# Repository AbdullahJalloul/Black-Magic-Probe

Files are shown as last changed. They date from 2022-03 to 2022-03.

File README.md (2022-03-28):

# ISO Black Magic Probe

**Black Magic Probe hardware features:**

*  On board implementation of JTAG (Joint Test Access Group) protocol
*  On board implementation of the SWD (Serial Wire Debug) protocol
*  High speed data interface to the Device Under Test 4.5MBit
*  On board implementation of the GNU Debugger Server protocol (no need for OpenOCD) works with stock arm-none-eabi-gdb (no patches or plugins needed)
*  Automatic detection of the Device Under Test (no need for config files)
*  Frontend Level shifter. Usable with targets that run on voltages as low as 1.7V and as high as 5V.
*  There is experimental support for Cortex-A (ARMv7-A architecture). This is being used with success on Xilinx Zynq-7000 SoC (Dual-core Cortex-A9) and Raspberry Pi 2 (Quad-core Cortex-A7).
*  Semihosting IO support (allows execution of print, read, open, system calls on the host through the JTAG/SWD interface)
*  Interface to the host computer is a standard USB CDC ACM device (virtual serial port), which does not require special drivers on Linux or MacOS.
*  Auxiliary UART interface. Black Magic Probe can be used as a USB to Serial adapter at the same time together with the JTAG/SWD interface.
*  Implements USB DFU class for easy firmware upgrade as updates become available.
*  Works with Windows, Linux and MacOS environments.

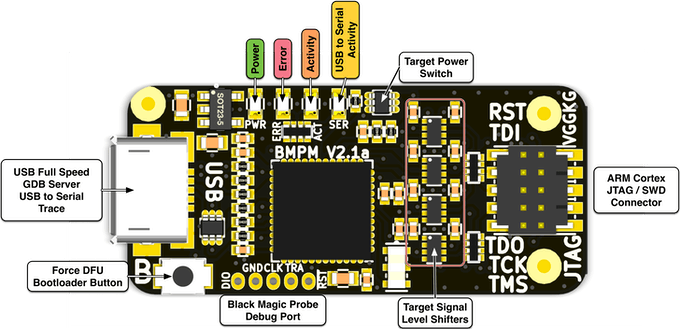
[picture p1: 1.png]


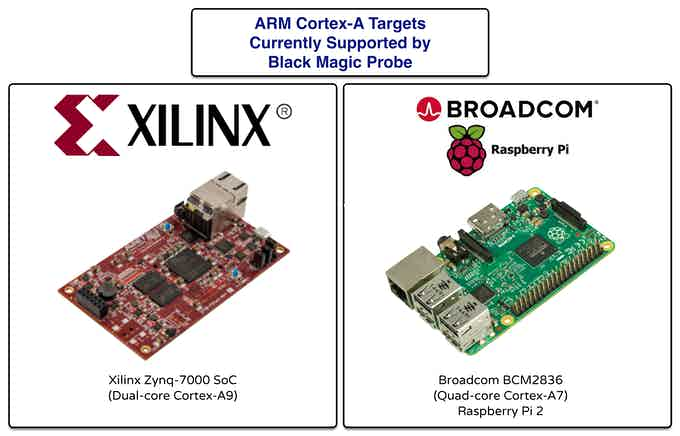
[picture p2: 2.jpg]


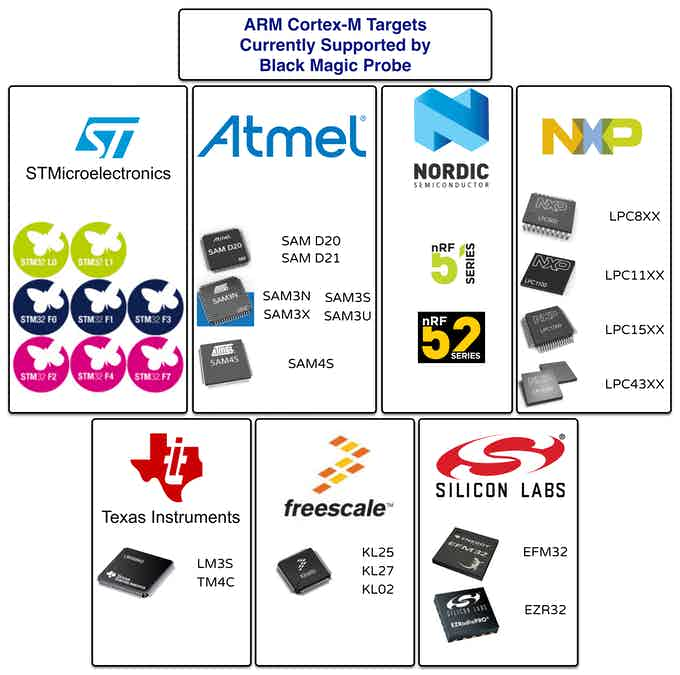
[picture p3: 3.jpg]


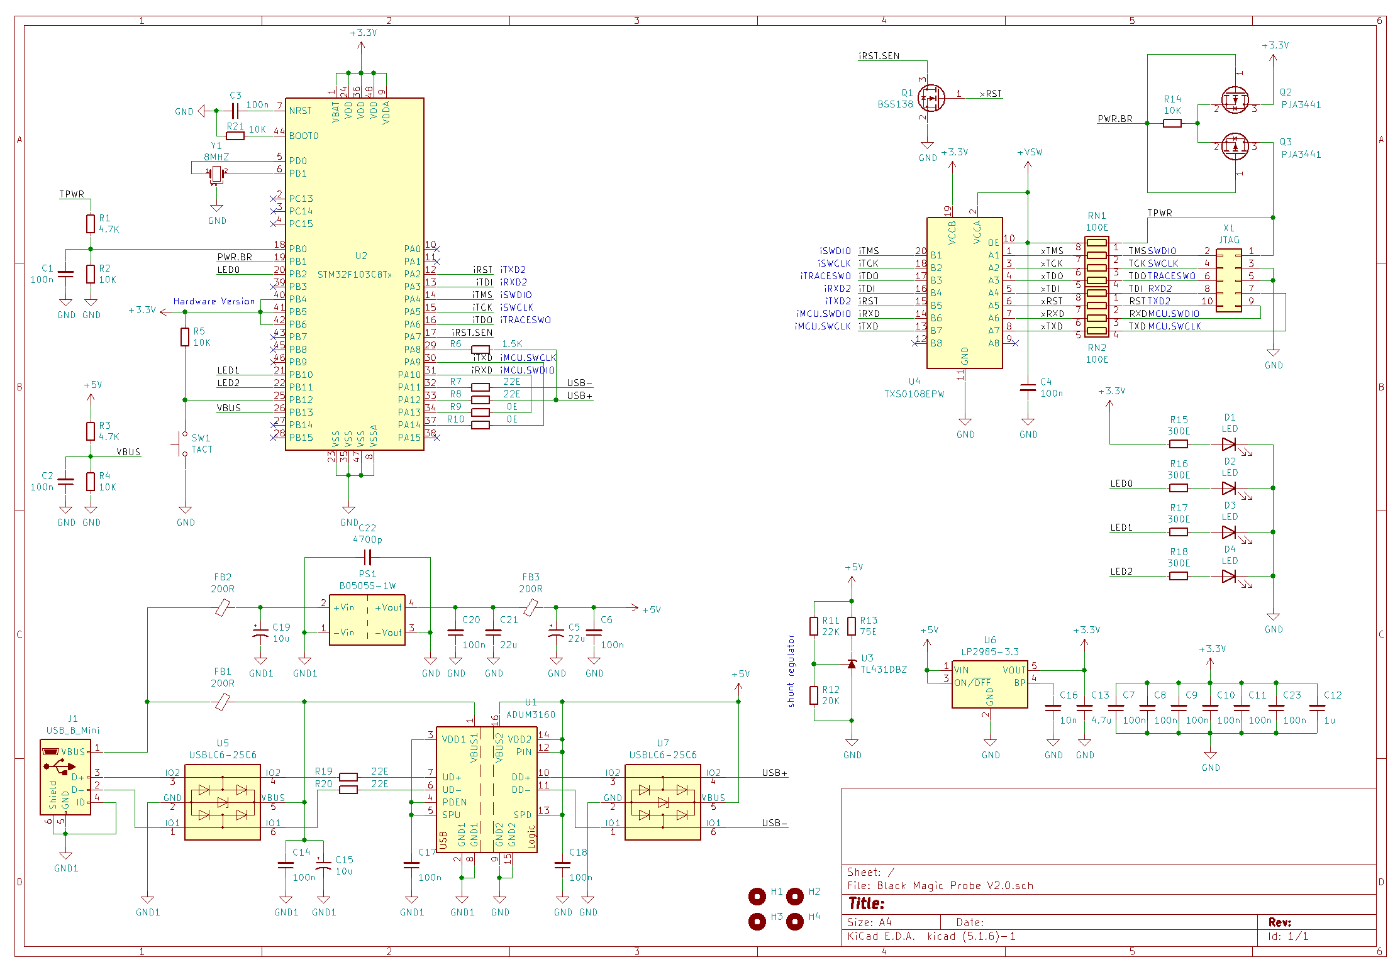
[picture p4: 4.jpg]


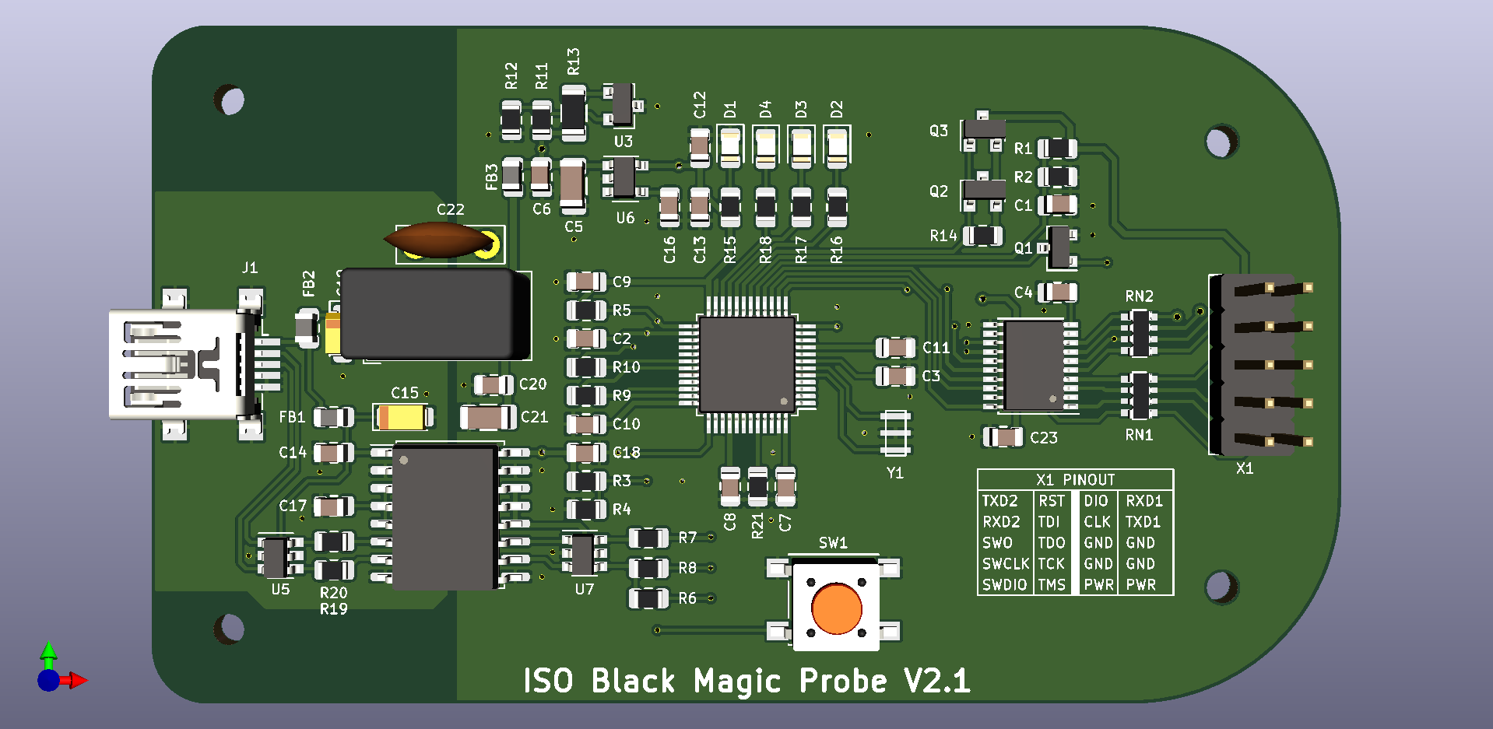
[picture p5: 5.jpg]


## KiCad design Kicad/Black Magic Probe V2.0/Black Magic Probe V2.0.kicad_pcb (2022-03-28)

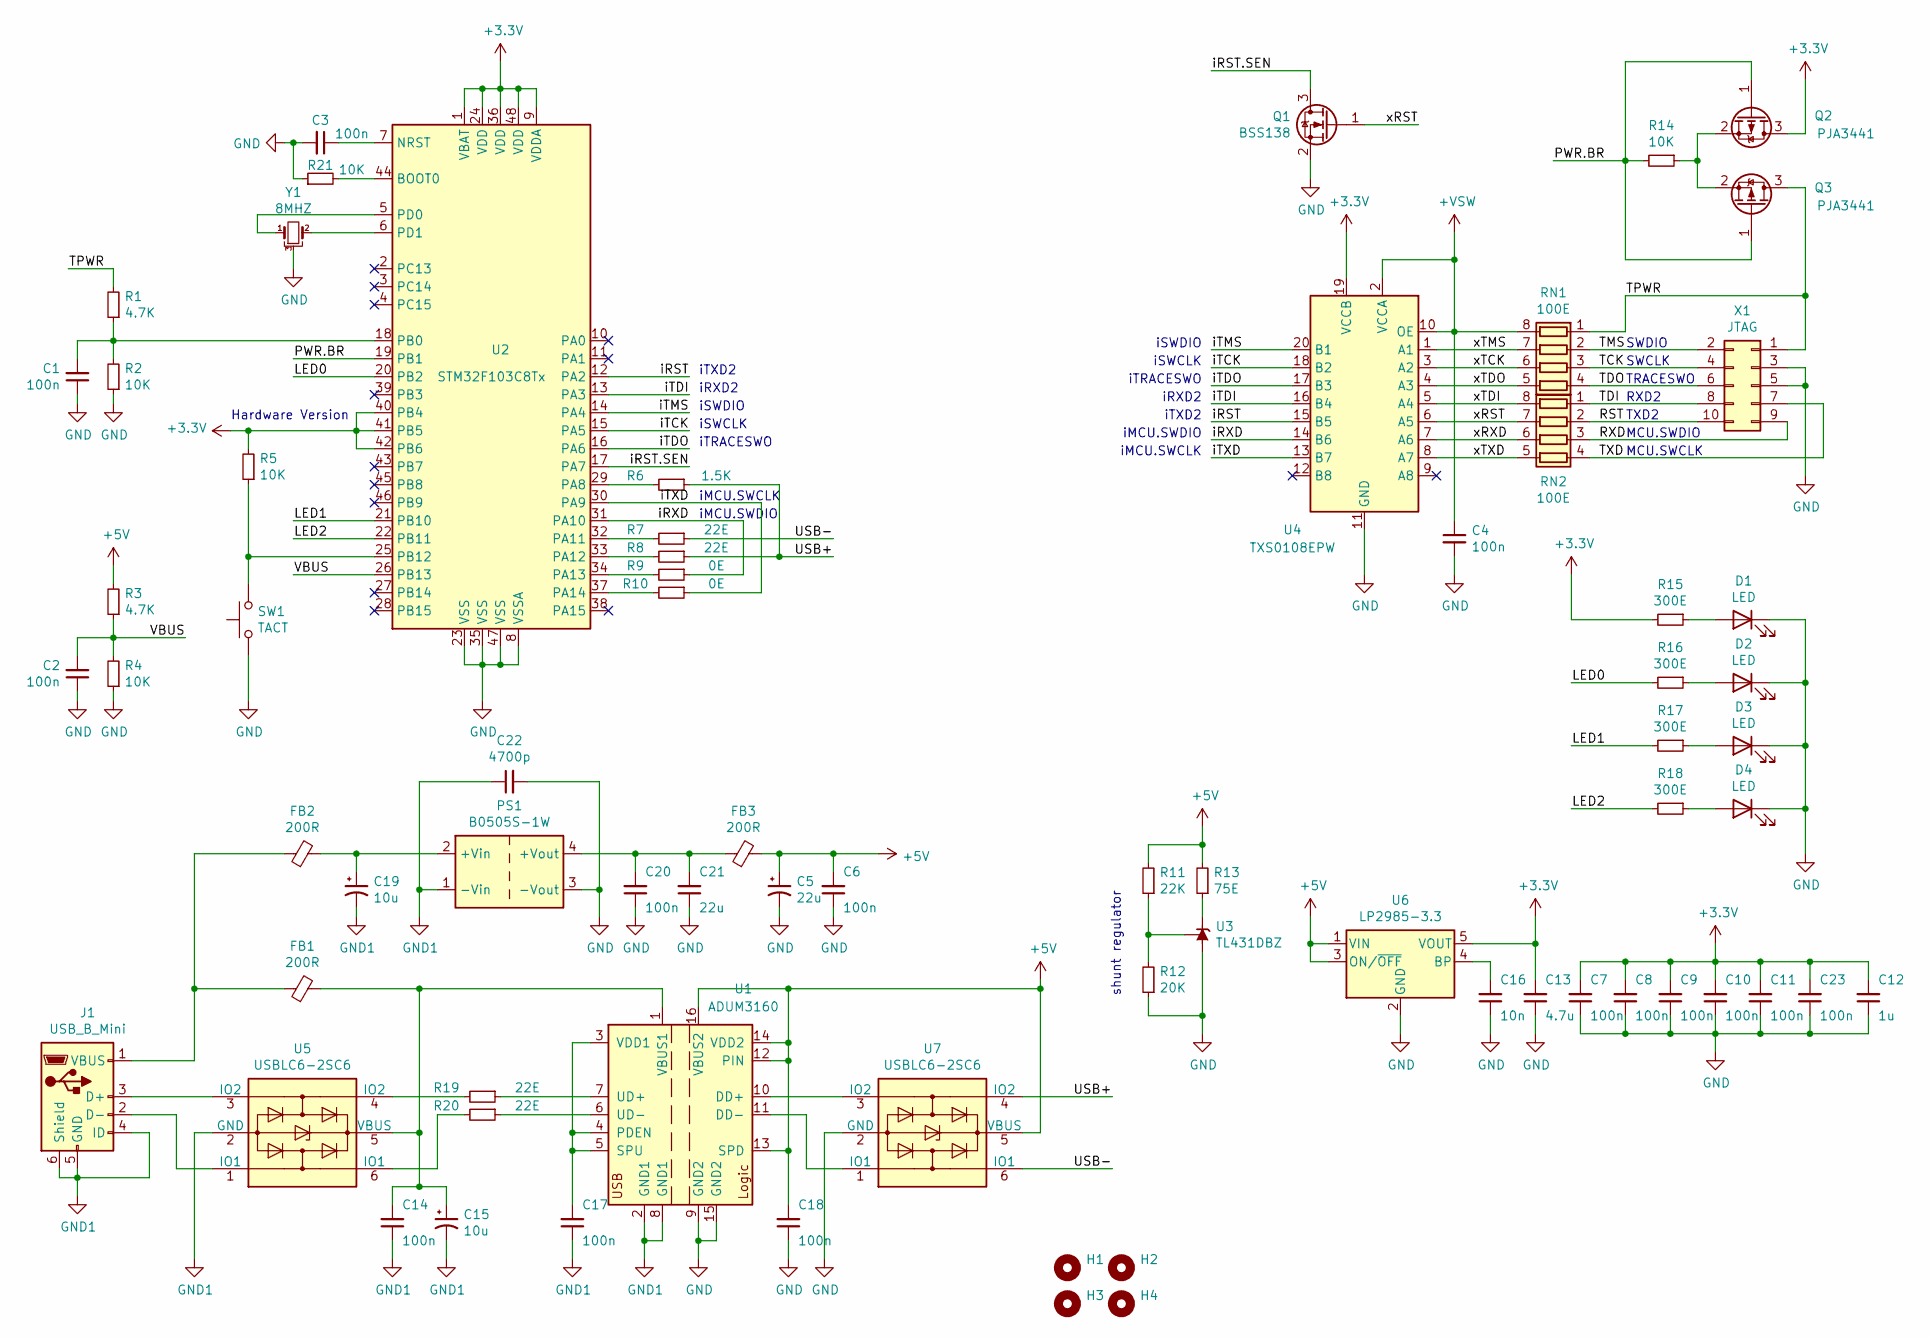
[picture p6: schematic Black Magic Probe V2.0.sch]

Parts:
C1, C2, C3, C4, C6, C7, C8, C9, C10, C11, C14, C17, C18, C20, C23: 100n; C_0805_2012Metric
C5, C21: 22u; C_1206_3216Metric
C12: 1u; C_0805_2012Metric
C13: 4.7u; C_0805_2012Metric
C15: 10u; CP_EIA-3216-10_Kemet-I
C16: 10n; C_0805_2012Metric
C19: 10u; CP_EIA-3216-18_Kemet-A
C22: 4700p; C_Disc_D7.5mm_W2.5mm_P5.00mm
D1, D2, D3, D4: LED; LED_0805_2012Metric
FB1, FB2, FB3: 200R; L_0805_2012Metric
H1, H2, H3, H4: MountingHole; MountingHole_2.2mm_M2
J1: USB_B_Mini; USB_Mini-B_Lumberg_2486_01_Horizontal
PS1: B0505S-1W; Converter_DCDC_Murata_MEE1SxxxxSC_THT
Q1: BSS138; SOT-23
Q2, Q3: PJA3441; SOT-23
R1, R3: 4.7K; R_0805_2012Metric
R2, R4, R5, R14, R21: 10K; R_0805_2012Metric
R6: 1.5K; R_0805_2012Metric
R7, R8, R19, R20: 22E; R_0805_2012Metric
R9, R10: 0E; R_0805_2012Metric
R11: 22K; R_0805_2012Metric
R12: 20K; R_0805_2012Metric
R13: 75E; R_1206_3216Metric
R15, R16, R17, R18: 300E; R_0805_2012Metric
RN1, RN2: 100E; R_Array_Convex_4x0603
SW1: TACT; SW_SPST_PTS645
U1: ADUM3160; SOIC-16W_7.5x10.3mm_P1.27mm
U2: STM32F103C8Tx; LQFP-48_7x7mm_P0.5mm
U3: TL431DBZ; SOT-23
U4: TXS0108EPW; SSOP-20_4.4x6.5mm_P0.65mm
U5, U7: USBLC6-2SC6; SOT-23-6
U6: LP2985-3.3; SOT-23-5
X1: JTAG; PinHeader_2x05_P2.54mm_Vertical
Y1: 8MHZ; CSTCE8M00G52

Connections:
+3V3: C7.2, C8.2, C9.2, C10.2, C11.2, C12.2, C13.2, C23.2, Q2.3 (D), R5.2, R15.2, U2.1 (VBAT), U2.9 (VDDA), U2.24 (VDD), U2.36 (VDD), U2.40 (PB4), U2.41 (PB5), U2.42 (PB6), U2.48 (VDD), U4.19 (VCCB), U6.5 (VOUT)
+5V: C5.1, C6.2, C18.2, FB3.2, R3.2, R11.2, R13.2, U1.12 (PIN), U1.13 (SPD), U1.14 (VDD2), U1.16 (VBUS2), U6.1 (VIN), U6.3 (ON/~OFF~), U7.5 (VBUS)
+VSW: C4.1, RN1.8 (R1.2), U4.2 (VCCA), U4.10 (OE)
/LED0: R16.2, U2.20 (PB2)
/LED1: R17.2, U2.21 (PB10)
/LED2: R18.2, U2.22 (PB11)
/PWR.BR: Q2.1 (G), Q3.1 (G), R14.2, U2.19 (PB1)
/RST: RN2.2 (R2.1), X1.10
/RXD: RN2.3 (R3.1), X1.9
/TCK: RN1.3 (R3.1), X1.4
/TDI: RN2.1 (R1.1), X1.8
/TDO: RN1.4 (R4.1), X1.6
/TMS: RN1.2 (R2.1), X1.2
/TPWR: Q3.3 (D), R1.2, RN1.1 (R1.1), X1.1
/TXD: RN2.4 (R4.1), X1.7
/USB+: R6.1, R8.1, U7.4 (IO2)
/USB-: R7.1, U7.6 (IO1)
/VBUS: C2.2, R3.1, R4.2, U2.26 (PB13)
/iRST: U2.12 (PA2), U4.15 (B5)
/iRST.SEN: Q1.3 (D), U2.17 (PA7)
/iRXD: R9.1, U2.31 (PA10), U4.14 (B6)
/iTCK: U2.15 (PA5), U4.18 (B2)
/iTDI: U2.13 (PA3), U4.16 (B4)
/iTDO: U2.16 (PA6), U4.17 (B3)
/iTMS: U2.14 (PA4), U4.20 (B1)
/iTXD: R10.1, U2.30 (PA9), U4.13 (B7)
/xRST: Q1.1 (G), RN2.7 (R2.2), U4.6 (A5)
/xRXD: RN2.6 (R3.2), U4.7 (A6)
/xTCK: RN1.6 (R3.2), U4.3 (A2)
/xTDI: RN2.8 (R1.2), U4.5 (A4)
/xTDO: RN1.5 (R4.2), U4.4 (A3)
/xTMS: RN1.7 (R2.2), U4.1 (A1)
/xTXD: RN2.5 (R4.2), U4.8 (A7)
GND: C1.1, C2.1, C3.2, C4.2, C5.2, C6.1, C7.1, C8.1, C9.1, C10.1, C11.1, C12.1, C13.1, C16.1, C18.1, C20.1, C21.1, C22.2, C23.1, D1.1 (K), D2.1 (K), D3.1 (K), D4.1 (K), PS1.3 (-Vout), Q1.2 (S), R2.1, R4.1, R12.1, R21.1, SW1.1, U1.9 (GND2), U1.15 (GND2), U2.8 (VSSA), U2.23 (VSS), U2.35 (VSS), U2.47 (VSS), U3.3 (A), U4.11 (GND), U6.2 (GND), U7.2 (GND), X1.3, X1.5, Y1.3
GND1: C14.1, C15.2, C17.1, C19.2, C22.1, J1.4 (ID), J1.5 (GND), J1.6 (Shield), PS1.1 (-Vin), U1.2 (GND1), U1.8 (GND1), U5.2 (GND)
unnamed: C1.2, R1.1, R2.2, U2.18 (PB0)
unnamed: C3.1, U2.7 (NRST)
unnamed: C14.2, C15.1, FB1.2, U1.1 (VBUS1), U5.5 (VBUS)
unnamed: C16.2, U6.4 (BP)
unnamed: C17.2, U1.3 (VDD1), U1.4 (PDEN), U1.5 (SPU)
unnamed: C19.1, FB2.2, PS1.2 (+Vin)
unnamed: C20.2, C21.2, FB3.1, PS1.4 (+Vout)
unnamed: D1.2 (A), R15.1
unnamed: D2.2 (A), R16.1
unnamed: D3.2 (A), R17.1
unnamed: D4.2 (A), R18.1
unnamed: FB1.1, FB2.1, J1.1 (VBUS)
unnamed: J1.2 (D-), U5.1 (IO1)
unnamed: J1.3 (D+), U5.3 (IO2)
unnamed: Q2.2 (S), Q3.2 (S), R14.1
unnamed: R5.1, SW1.2, U2.25 (PB12)
unnamed: R6.2, U2.29 (PA8)
unnamed: R7.2, U2.32 (PA11)
unnamed: R8.2, U2.33 (PA12)
unnamed: R9.2, U2.34 (PA13)
unnamed: R10.2, U2.37 (PA14)
unnamed: R11.1, R12.2, U3.2 (REF)
unnamed: R13.1, U3.1 (K)
unnamed: R19.1, U1.7 (UD+)
unnamed: R19.2, U5.4 (IO2)
unnamed: R20.1, U1.6 (UD-)
unnamed: R20.2, U5.6 (IO1)
unnamed: R21.2, U2.44 (BOOT0)
unnamed: U1.10 (DD+), U7.3 (IO2)
unnamed: U1.11 (DD-), U7.1 (IO1)
unnamed: U2.5 (PD0), Y1.1
unnamed: U2.6 (PD1), Y1.2

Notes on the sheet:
SWDIO
SWCLK
TRACESWO
RXD2
TXD2
MCU.SWDIO
MCU.SWCLK
iMCU.SWCLK
iMCU.SWDIO
iSWDIO
iSWCLK
iTRACESWO
iRXD2
iTXD2
Hardware Version
shunt regulator

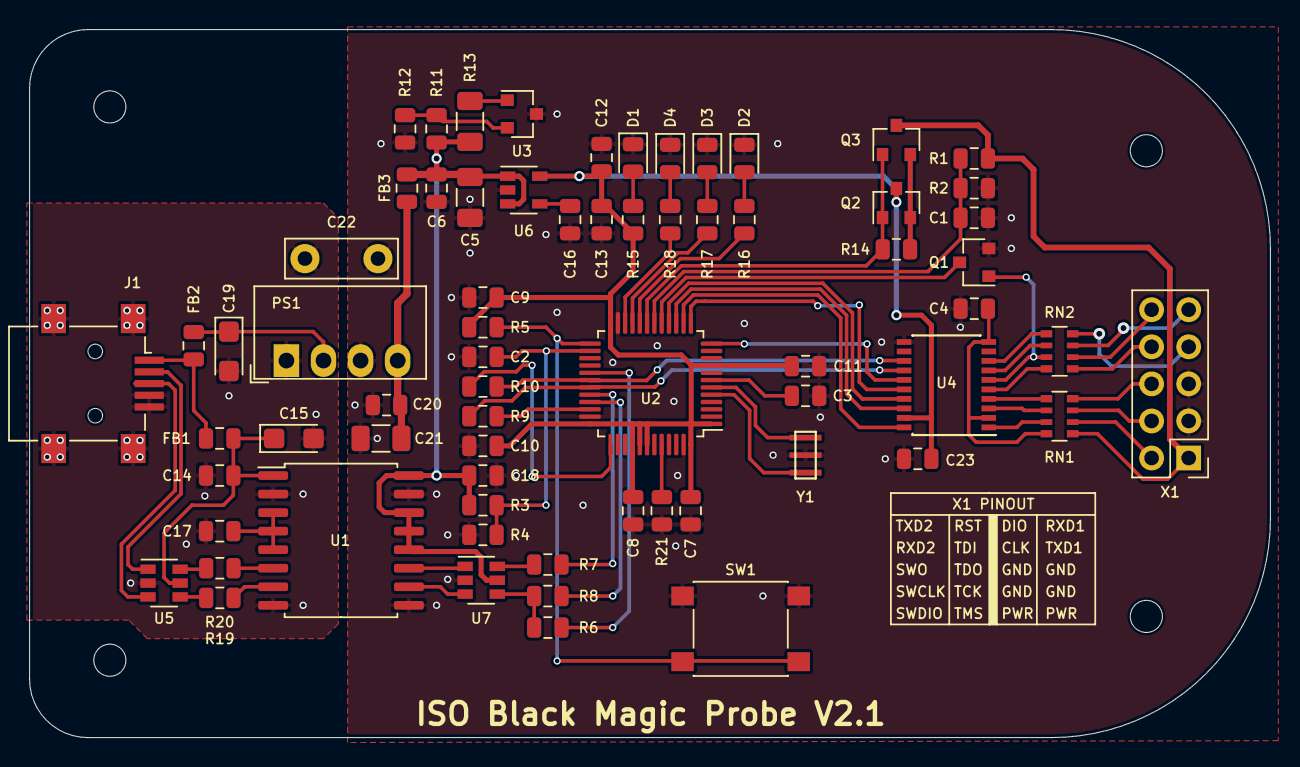
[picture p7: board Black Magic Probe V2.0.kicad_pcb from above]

Board: 2 copper layers, 85.0 x 48.5 mm, 72 parts (0 on the bottom side), 67 nets.

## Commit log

2022-03-28 Update PCB
    [Black Magic Probe V2.0-B_Cu.gbr, Black Magic Probe V2.0-B_Mask.gbr, Black Magic Probe V2.0-B_SilkS.gbr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]
2022-03-28 add sch and PCB
